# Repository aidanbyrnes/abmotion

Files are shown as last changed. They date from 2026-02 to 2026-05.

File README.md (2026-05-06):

abmotion
=============
Wireless motion devices designed for dance and interactive-immersive art.

Based on the Microbots CodeCell C3 and C6, which are based on the ESP32 C3 and C6 respectively, each device reports its own measured RMS of acceleration, rotation quaternion, and detected transients. Additionally, they can be configured for spatial tracking if connected to a UWB board and additional UWB base stations.

A wired receiver connects up to 20 devices through ESP-NOW. Included patches allow for communication with these devices through Max/MSP.

Video of abmotion demo (https://www.youtube.com/watch?v=6O_tBzo_ZVA)
*Video of Lily Prescott and Grace Ferrell demonstrating sonified dance through transient detection on abmotion devices.*

## Hardware

* [Microbots CodeCell C3](https://microbots.io/products/codecell?variant=49714638782797) or [C6](https://microbots.io/products/codecell-c6)
* [TinyCircuits 3.7V 500mAh Battery](https://www.digikey.com/en/products/detail/tinycircuits/ASR00035/9808767)
* Spatial (tag & base stations): [Ultra-Wide-Band Positioning Development Kit (UWB, BU-03)
](https://core-electronics.com.au/ultra-wide-band-module-development-kit-bu03.html)
* Receiver: any ESP32 or ESP8266 device
  * Recommended (compatible with included case): ESP32-C3 Super Mini Development Board with external antenna
## Dependencies
* Max/MSP
  * [CNMAT-Externs](https://github.com/CNMAT/CNMAT-Externs) by CNMAT
  * [ODOT](https://github.com/CNMAT/CNMAT-odot) by CNMAT
  * [Spat](https://forum.ircam.fr/projects/detail/spat/) by IRCAM

## Contact

contact@aidanbyrnes.net

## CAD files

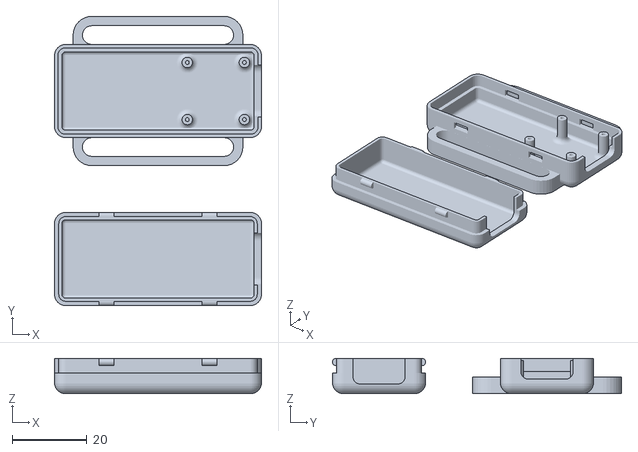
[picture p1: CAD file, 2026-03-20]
case.stl
55.5 x 77.5 x 9.50

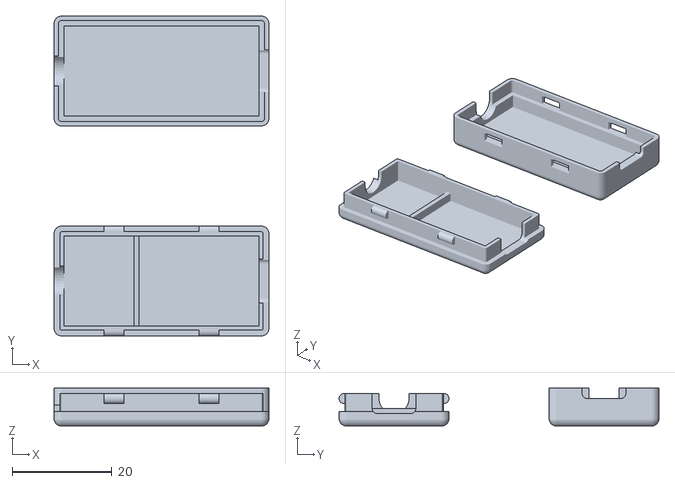
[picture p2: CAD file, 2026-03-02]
receiver.stl
43.0 x 64.0 x 7.59

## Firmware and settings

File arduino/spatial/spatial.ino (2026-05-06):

// Uses code by Jaryd from Core Electronics
// https://core-electronics.com.au/guides/sensors/diy-2d-and-3d-spatial-tracking-with-ultra-wideband-arduino-and-pico-guide/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

#include <WiFi.h>
#include <esp_now.h>
#include <CodeCell.h>

#define RX_PIN 21
#define TX_PIN 22

#define DEVICE_ID 9
#define SAMPLERATE 40 // Hz
#define SEND_RATE 20
#define WAIT_N_FRAMES (SAMPLERATE / SEND_RATE)

#define RMS_WINDOW 1000 // milliseconds (substantially higher for torso sensor due to gait)
#define DEADZONE .1
#define LP_CUTOFF_FREQ 2.0f
#define MAX_FROZEN 5
#define RADIO_OFF_RESTART_MS (10UL * 60UL * 1000UL)
#define STILL_TIMEOUT_MS 30000

uint8_t receiverMAC[] = {0xAC, 0xA7, 0x04, 0xD4, 0xDA, 0x88};

#define SENSOR_DATA_LEN 8
#define ID_OFFSET UINT_MAX / 2

typedef struct __attribute__((packed)) {
  unsigned int deviceID;
  unsigned int battery;
  float data[SENSOR_DATA_LEN];
} DataPacket;

DataPacket uwbPacket;
DataPacket motionPacket;

CodeCell myCodeCell;

bool radio_on = true;
unsigned long radioOffSince = 0;

int frame_counter = 1; // don't send packet immediately on boot
bool is_idle = false;
bool is_charging = false;

#define RMS_WINDOW_SAMPS ((int)((float)RMS_WINDOW / 1000.0f * SAMPLERATE))

float rms_buffer[RMS_WINDOW_SAMPS] = {0.0f};
int rms_head = 0;
float rms_sum_sq = 0.0f;
float rms = 0.0;
float lp = 0.0;
float lp_alpha = 0.0;

unsigned long still_since = 0;

float ax = 0, ay = 0, az = 0;
float ax_hist = 0, ay_hist = 0, az_hist = 0;
int frozen_frames = 0;

float calc_lp_alpha(float cutoff_freq, float sample_rate) {
  float rc = 1.0f / (2.0f * PI * cutoff_freq);
  float dt = 1.0f / sample_rate;
  return dt / (rc + dt);
}

void radio_start() {
  WiFi.mode(WIFI_STA);
  esp_now_init();

  esp_now_peer_info_t peerInfo = {};
  memcpy(peerInfo.peer_addr, receiverMAC, 6);
  peerInfo.channel = 0;
  peerInfo.encrypt = false;

  esp_now_add_peer(&peerInfo);
  radio_on = true;
  radioOffSince = 0;
}

void radio_stop() {
  esp_now_deinit();
  WiFi.disconnect(true);
  WiFi.mode(WIFI_OFF);
  radio_on = false;
  if (radioOffSince == 0) radioOffSince = millis();
}

void calc_motion_scalar() {
  ax_hist = ax;
  ay_hist = ay;
  az_hist = az;

  myCodeCell.Motion_LinearAccRead(ax, ay, az);

  float new_val = ax * ax + ay * ay + az * az;
  if (!isfinite(new_val)) new_val = 0.0f;

  rms_sum_sq -= rms_buffer[rms_head];
  rms_buffer[rms_head] = new_val;
  rms_sum_sq += new_val;
  rms_head = (rms_head + 1) % RMS_WINDOW_SAMPS;

  if (rms_sum_sq < 0.0f) rms_sum_sq = 0.0f;

  rms = sqrt(rms_sum_sq / RMS_WINDOW_SAMPS);
  rms *= (rms >= DEADZONE);

  float new_lp = rms * lp_alpha + (1.0f - lp_alpha) * lp;
  if (isfinite(new_lp)) lp = new_lp;
}

bool freeze_check() {
  if (ax == ax_hist && ay == ay_hist && az == az_hist) {
    if (frozen_frames > MAX_FROZEN) {
      Serial.println(">> Freeze detected");
      ESP.restart();
    } else {
      frozen_frames++;
      return true;
    }
  } else {
    frozen_frames = 0;
  }

  return false;
}

void charging_check() {
  if (myCodeCell.PowerStateRead() == 5) {
    myCodeCell.LED_SetBrightness(2);
    myCodeCell.LED_Breathing(LED_COLOR_GREEN);
    is_charging = true;
  } else {
    is_charging = false;
  }
}

void idle_check() {
  if (rms < DEADZONE) {
    if (still_since == 0) still_since = millis();
    if (millis() - still_since >= STILL_TIMEOUT_MS) is_idle = true;
  } else {
    still_since = 0;
    is_idle = false;
  }
}

bool decodeUwbDistances(uint8_t* data, int dataLen, float* distances) {
  for (int i = 0; i < SENSOR_DATA_LEN; i++) distances[i] = -1.0;

  if (dataLen < 35) return false;
  if (data[0] != 0xaa || data[1] != 0x25 || data[2] != 0x01) return false;

  for (int i = 0; i < SENSOR_DATA_LEN; i++) {
    int byteOffset = 3 + (i * 4);
    if (byteOffset + 3 < dataLen) {
      uint32_t distanceRaw = data[byteOffset] |
                            (data[byteOffset + 1] << 8) |
                            (data[byteOffset + 2] << 16) |
                            (data[byteOffset + 3] << 24);
      distances[i] = (distanceRaw > 0) ? distanceRaw / 1000.0 : -1.0;
    }
  }
  return true;
}

void setup() {
  Serial.begin(115200);

  myCodeCell.Init(MOTION_LINEAR_ACC);
  myCodeCell.LED_SetBrightness(0);

  Serial1.begin(115200, SERIAL_8N1, RX_PIN, TX_PIN);

  lp_alpha = calc_lp_alpha(LP_CUTOFF_FREQ, SAMPLERATE);

  radio_start();

  uwbPacket.deviceID = DEVICE_ID + ID_OFFSET;
  motionPacket.deviceID = DEVICE_ID;
}

void loop() {
  if (myCodeCell.Run(SAMPLERATE)) {
    myCodeCell.LED_SetBrightness(0);

    // Restart if radio has been off too long
    if (!radio_on && radioOffSince > 0 && millis() - radioOffSince >= RADIO_OFF_RESTART_MS) {
      ESP.restart();
    }

    charging_check();
    calc_motion_scalar();
    idle_check();

    freeze_check();

    if (is_charging || is_idle) {
      if (radio_on) radio_stop();
      return;
    } else if (!is_charging && !is_idle && !radio_on) {
      radio_start();
    }

    // Read and decode incoming UWB serial data
    static uint8_t buffer[256];
    static int bufferIndex = 0;
    static bool messageStarted = false;
    static float latestDistances[SENSOR_DATA_LEN] = {-1.0};
    static bool hasValidData = false;

    while (Serial1.available()) {
      uint8_t incomingByte = Serial1.read();

      if (!messageStarted && incomingByte == 0xAA) {
        messageStarted = true;
        bufferIndex = 0;
        buffer[bufferIndex++] = incomingByte;
      } else if (messageStarted) {
        buffer[bufferIndex++] = incomingByte;

        if (bufferIndex >= 35) {
          hasValidData = decodeUwbDistances(buffer, bufferIndex, latestDistances);
          messageStarted = false;
          bufferIndex = 0;
        }

        if (bufferIndex >= 256) {
          messageStarted = false;
          bufferIndex = 0;
        }
      }
    }

    if (frame_counter == 0 && radio_on) {
      unsigned int batt = (unsigned int)min((int)myCodeCell.BatteryLevelRead(), 100);

      // Send UWB distances packet
      if (hasValidData) {
        uwbPacket.battery = batt;
        memcpy(uwbPacket.data, latestDistances, sizeof(latestDistances));
        esp_now_send(receiverMAC, (uint8_t*)&uwbPacket, sizeof(uwbPacket));
      }

      // Send motion scalar packet (no ID offset)
      motionPacket.battery = batt;
      motionPacket.data[0] = lp;
      esp_now_send(receiverMAC, (uint8_t*)&motionPacket, sizeof(motionPacket));
    }

    frame_counter = (frame_counter + 1) % WAIT_N_FRAMES;
  }
}

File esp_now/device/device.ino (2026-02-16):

#include <WiFi.h>
#include <esp_now.h>
#include <CodeCell.h>
#include <freertos/FreeRTOS.h>
#include <freertos/task.h>
#include <freertos/queue.h>

#define DEVICE_ID 1
#define SAMPLERATE 30 //Hz

#define SEND_RATE 10 //Hz

#define RMS_WINDOW 100 //milliseconds
#define DEADZONE .1
#define LP_CUTOFF_FREQ 2.0f  // Low-pass cutoff frequency in Hz
#define SLEEP_TIMER 5 // How many seconds to wait until sleep when device is active
#define MAX_FROZEN 5 // How many consecutive frames are allowed to be the same before sensor is considered frozen

CodeCell myCodeCell;

uint8_t receiverMAC[] = {0x28, 0x37, 0x2F, 0xC9, 0x04, 0x24};  // <-- change to receiver MAC

typedef struct __attribute__((packed)) {
  unsigned int deviceID;
  float motion_scalar;
  float qw;
  float qx;
  float qy;
  float qz;
  unsigned int battery;
} DataPacket;

typedef struct {
  float motion;
  float qw;
  float qx;
  float qy;
  float qz;
  unsigned int battery;
} SensorData;

TaskHandle_t sensorTaskHandle = NULL;
TaskHandle_t espnowTaskHandle = NULL;

QueueHandle_t sensorDataQueue;

// motion processing
float motion_hist;
int rms_index = 0;
int rms_samps;
float rms_accum = 0.0;
float rms = 0.0;
float lp_hist = 0.0;
float lp = 0.0;
float lp_alpha = 0.0;
int stationary_frames = 0;
int frozen_frames = 0;

float ax = 0, ay = 0, az = 0;
float qw = 1, qx = 0, qy = 0, qz = 0;
float ax_hist = 0, ay_hist = 0, az_hist = 0;
float qw_hist = 1, qx_hist = 0, qy_hist = 0, qz_hist = 0;

float calc_lp_alpha(float cutoff_freq, float sample_rate) {
  float rc = 1.0f / (2.0f * PI * cutoff_freq);
  float dt = 1.0f / sample_rate;
  return dt / (rc + dt);
}

int calc_buffer_size(int sr){
  int size = (float)RMS_WINDOW / 1000.0f * sr;
  size = (size > 0) ? size : 1;
  return size;
}

float calc_motion_scalar(int sr = SAMPLERATE){
  ax_hist = ax;
  ay_hist = ay;
  az_hist = az;

  myCodeCell.Motion_LinearAccRead(ax, ay, az);
  rms_accum += ax * ax + ay * ay + az * az; //magnitude of accel squared

  rms_index++;
  rms_samps = calc_buffer_size(sr);
  if(rms_index == rms_samps){
    rms = sqrt(rms_accum / rms_samps);
    rms *= (rms >= DEADZONE);
    rms_index = 0;
    rms_accum = 0.0;
  }

  lp_hist = lp;
  lp = rms * lp_alpha + (1 - lp_alpha) * lp_hist;

  return lp;
}

void freeze_check(){
    if(ax == ax_hist && ay == ay_hist && az == az_hist && qw == qw_hist && qx == qx_hist && qy == qy_hist && qz == qz_hist){
      frozen_frames++;
      if(frozen_frames > MAX_FROZEN){
        Serial.println(">> Freeze detected");
        ESP.restart();
      }
    }
    else{
      frozen_frames = 0;
    }
}

void sensorTask(void *parameter) {
  TickType_t xLastWakeTime = xTaskGetTickCount();
  
  unsigned int sample_count = 0;
  const unsigned int send_interval = SAMPLERATE / SEND_RATE;
  
  SensorData data;
  
  while(1) {
    if(myCodeCell.Run(SAMPLERATE)) {
      motion_hist = data.motion;
      data.motion = calc_motion_scalar();

      qw_hist = qw;
      qx_hist = qx;
      qy_hist = qy;
      qz_hist = qz;
      myCodeCell.Motion_RotationVectorRead(qw, qx, qy, qz);

      // Check for frozen data
      freeze_check();

      // Check for sleep condition is device is still
      // if(data.motion < 0.001 || data.motion == motion_hist){
      //   if((float)stationary_frames / SAMPLERATE >= SLEEP_TIMER + RMS_WINDOW / 1000.){
      //     myCodeCell.SleepTimer(0);
      //   }
      //   else{
      //     stationary_frames++;
      //   }
      // }
      // else{
      //   stationary_frames = 0;
      // }
      
      sample_count++;
      
      if(sample_count >= send_interval) {
        data.qw = qw;
        data.qx = qx;
        data.qy = qy;
        data.qz = qz;

        data.battery = (unsigned int)myCodeCell.BatteryLevelRead();
        
        xQueueSend(sensorDataQueue, &data, 0);
        
        sample_count = 0;
      }
    }
  }
}

void espnowTask(void *parameter) {
  SensorData data;
  DataPacket packet;
  packet.deviceID = DEVICE_ID;
  
  while(1) {
    if(xQueueReceive(sensorDataQueue, &data, portMAX_DELAY) == pdTRUE) {
      packet.motion_scalar = data.motion;
      packet.qw = data.qw;
      packet.qx = data.qx;
      packet.qy = data.qy;
      packet.qz = data.qz;
      packet.battery = data.battery;
      
      esp_err_t result = esp_now_send(receiverMAC, (uint8_t*)&packet, sizeof(packet));
      if (result != ESP_OK) {
          Serial.printf(">> Send failed: %d\n", result);
      }
    }
  }
}

void setup() {
  Serial.begin(115200);
  myCodeCell.Init(MOTION_LINEAR_ACC + MOTION_ROTATION);
  myCodeCell.LED_SetBrightness(0);

  lp_alpha = calc_lp_alpha(LP_CUTOFF_FREQ, SAMPLERATE);

  // // Wait for some initial motion on startup
  // Serial.println(">> Waiting for motion..");
  // int init_sr = 10;
  // // Run once to update sensors
  // myCodeCell.Run(init_sr);
  // float init_motion = 0.0;
  // while(init_motion == 0.0){
  //   if(myCodeCell.Run(init_sr)){
  //     init_motion = calc_motion_scalar(init_sr);
  //   }
  // }
  // Serial.println(">> Motion detected");

  WiFi.mode(WIFI_STA);

  if (esp_now_init() != ESP_OK) {
    Serial.println("ESP-NOW init failed");
    return;
  }

  esp_now_peer_info_t peerInfo = {};
  memcpy(peerInfo.peer_addr, receiverMAC, 6);
  peerInfo.channel = 0;
  peerInfo.encrypt = false;

  esp_now_add_peer(&peerInfo);

  sensorDataQueue = xQueueCreate(2, sizeof(SensorData));

  xTaskCreate(
    sensorTask,
    "SensorTask",
    4096,
    NULL,
    2,
    &sensorTaskHandle
  );

  xTaskCreate(
    espnowTask,
    "ESPNowTask",
    4096,
    NULL,
    1,
    &espnowTaskHandle
  );
}

void loop() {
  vTaskDelay(portMAX_DELAY);
}

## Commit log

2026-01-30 Add Arduino code
2026-01-31 Prevent I2C timing bug
2026-01-31 Added sensor_pose abstraction
    A Max abstraction that detects wether a sensor is facing upwards, downwards, or outwards horizontally.
2026-01-31 Update README.md
    Add image of abmotion device to README
2026-02-01 Set samplerate back to 20Hz
2026-02-01 Update yaw related objects
2026-02-04 Gyro control objects
2026-02-16 Improved pitch tracking
2026-03-02 SLIP receiver & bundle of changes
    [receiver.stl]
2026-03-20 Spatial tracker and bundle of changes
    [case.stl]
